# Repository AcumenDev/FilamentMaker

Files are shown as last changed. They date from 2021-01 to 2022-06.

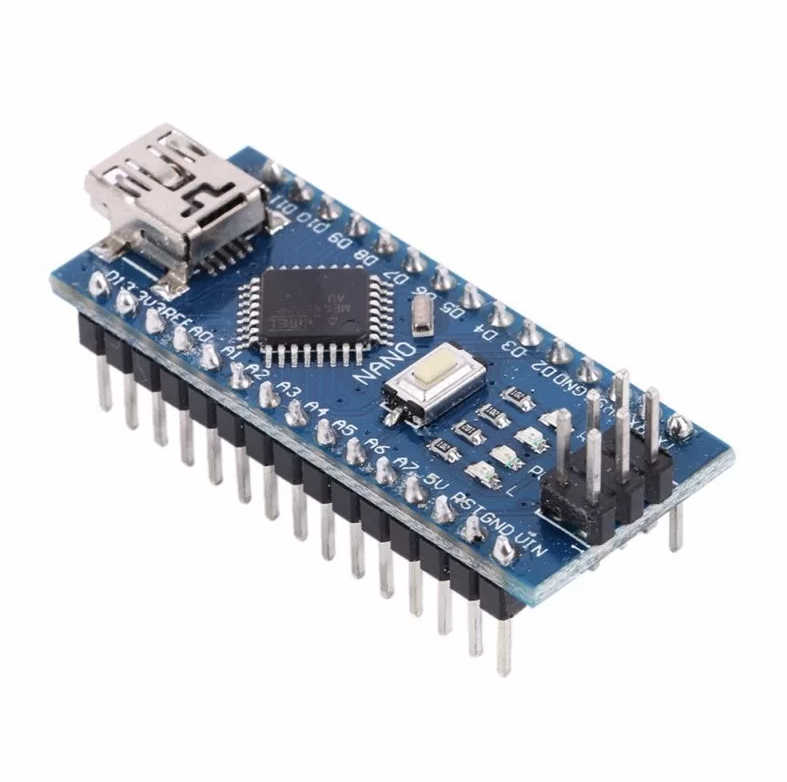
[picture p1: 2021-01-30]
images/nano.jpg

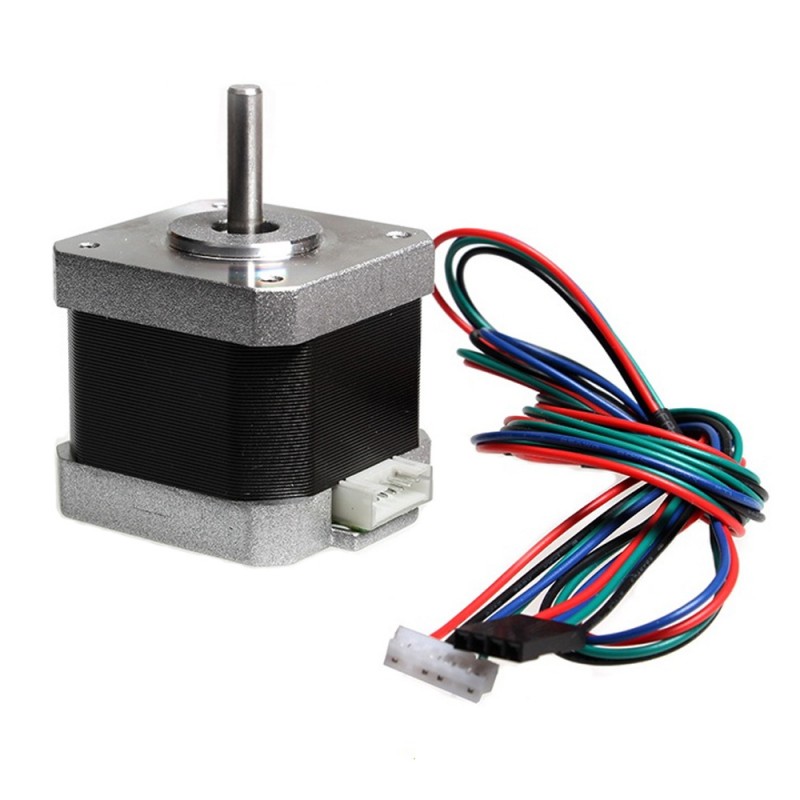
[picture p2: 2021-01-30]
images/stepper-nema17.jpg

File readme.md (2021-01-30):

Модели для печати

* редуктора 
* бутылкореза 
* корпуса для электроники 

находиться в папке models

Прошивка находится в папке src

Текущий список компонентов 

1. Arduino nano 328
1. Плата адаптера терминала WAVGAT для Arduino Nano 3,0
1. Модуль IRF520 для Arduino 
1. алюминиевый радиатор 15*10*25 мм для транзистора TO-220
1. Датчик температуры 100K Ohm NTC 3950 с кабелем
1. резистор 100 кОм
1. нагреватель для 3д принтера 12 вольт 40 ватт 
1. плата для драйвера шагового двигателя 
1. драйвер для шагового двигателя  A4988 или DRV8825 или TMC2208
1. Шаговый двигатель NEMA17 42N.cm 
1. блок питания 12 вольт 5 ампер

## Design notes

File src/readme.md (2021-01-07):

Для сборки и заливки в устройство понадобиться VSCode и плагин к нему platformio

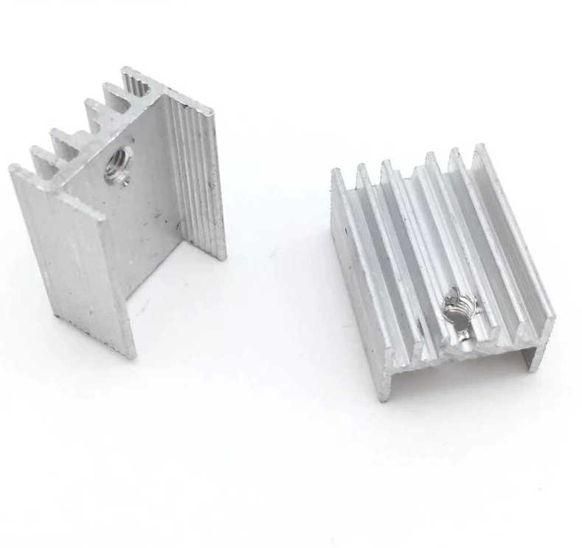
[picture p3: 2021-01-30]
images/radiator.jpg

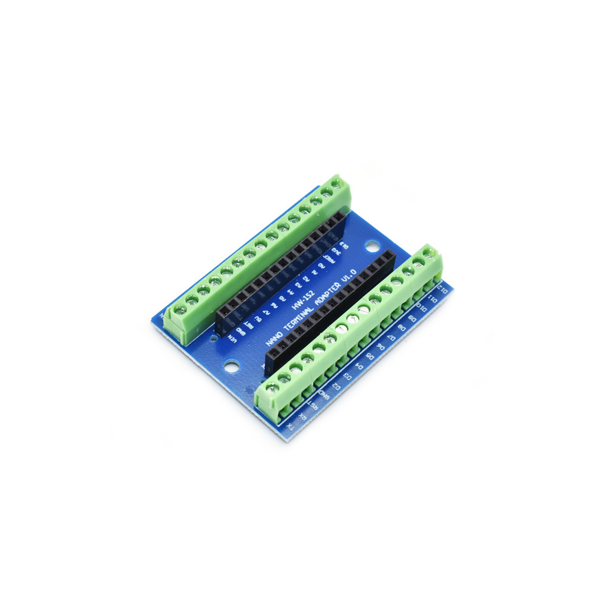
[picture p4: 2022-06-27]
images/Terminal-Adapter--Arduino-NanoV3.jpg

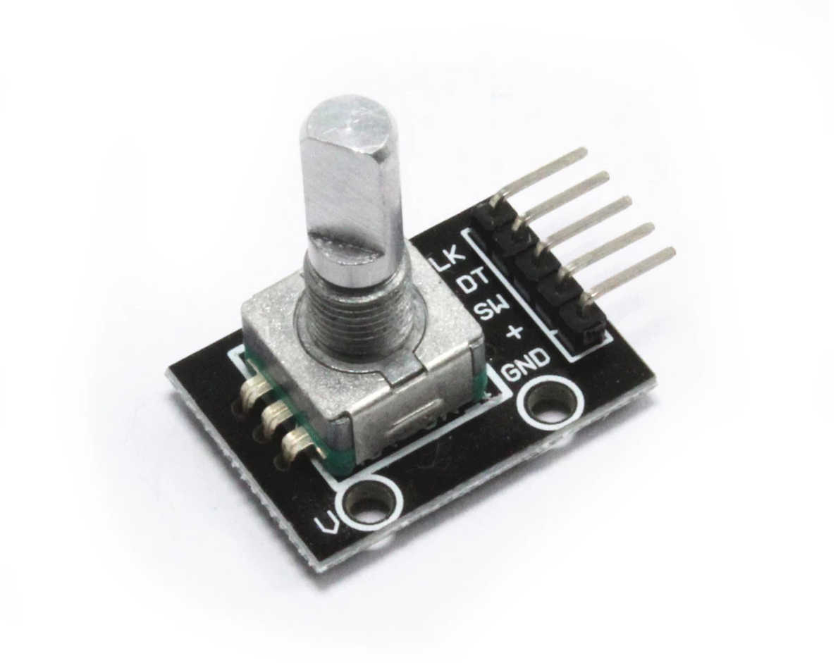
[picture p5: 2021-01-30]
images/encoder.jpg

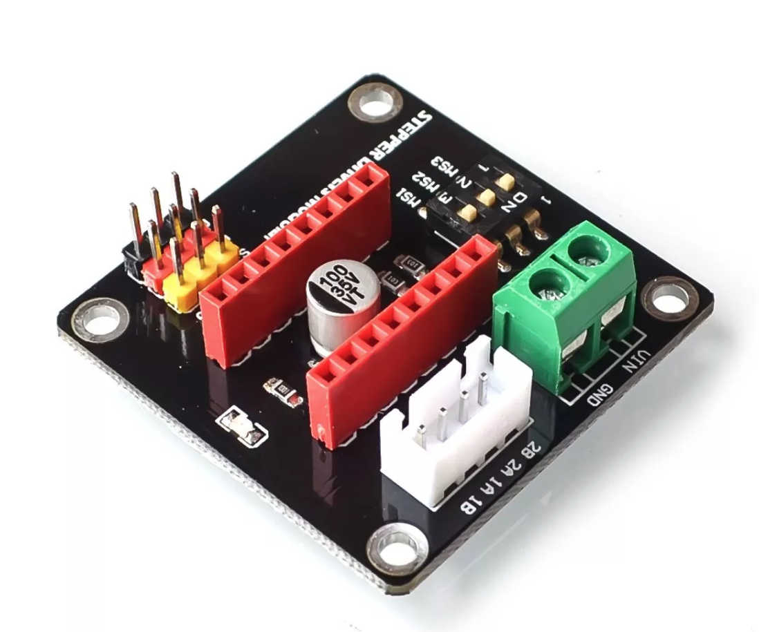
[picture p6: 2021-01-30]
images/driver-board.jpg

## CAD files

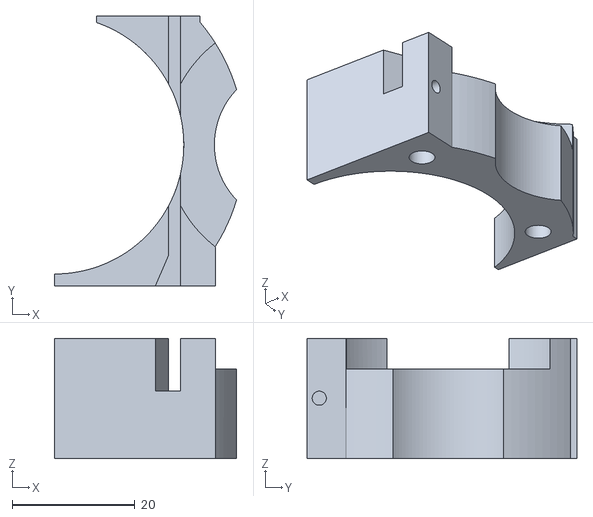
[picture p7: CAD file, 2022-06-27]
models/botle_cut/insert_6mm.stl
29.7 x 44.0 x 19.6

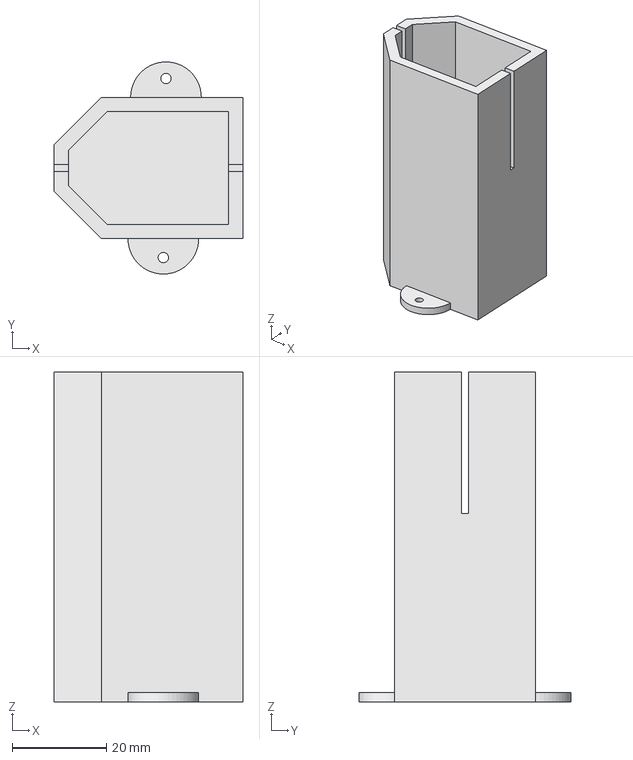
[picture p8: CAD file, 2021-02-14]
models/filter/filter.FCStd
40.0 x 45.0 x 70.0 mm

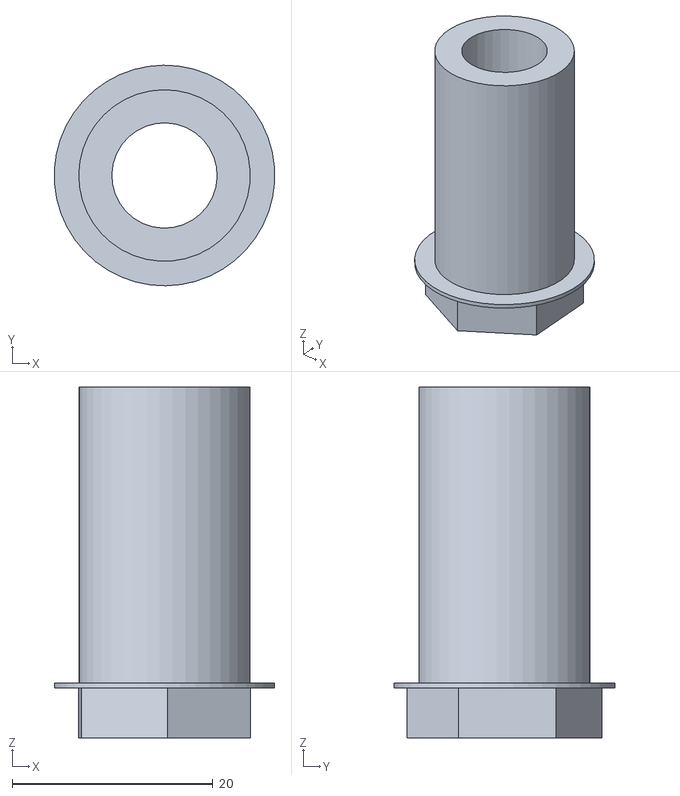
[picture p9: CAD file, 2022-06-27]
models/gearbox/new_gear_box_stl/New_gear_box-Modelinsert_bearing_for_spool001.stl
22.0 x 22.0 x 35.0

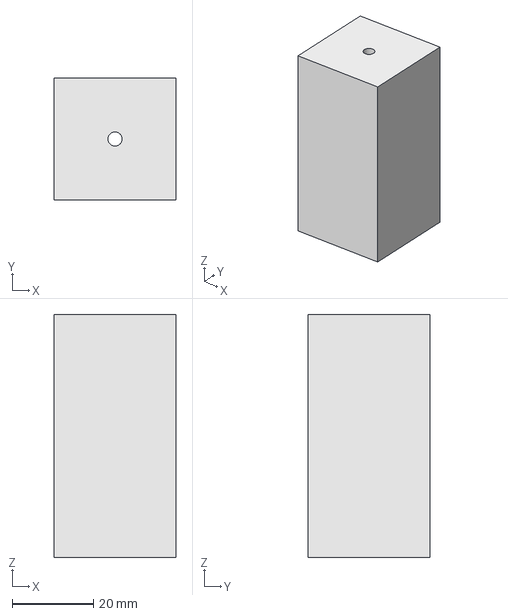
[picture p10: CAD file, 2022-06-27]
models/legs.FCStd
30.0 x 30.0 x 60.0 mm

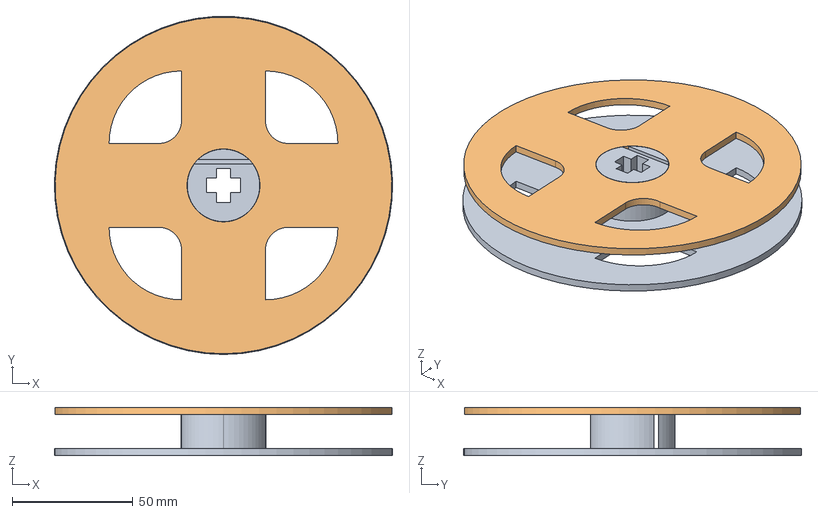
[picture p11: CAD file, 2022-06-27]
models/other/other.FCStd
140.0 x 139.9 x 20.0 mm

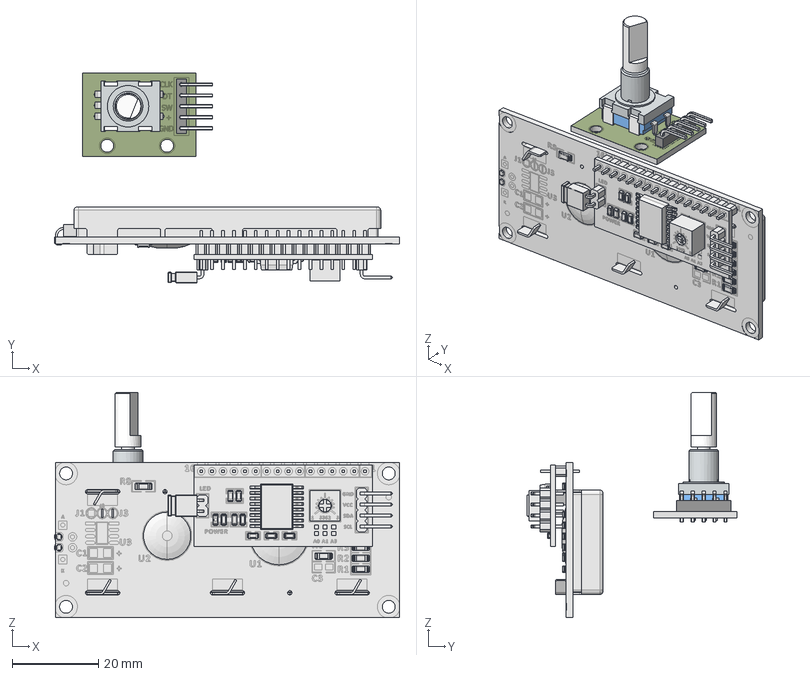
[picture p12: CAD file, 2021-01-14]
models/pcb_box/pcb_box.FCStd
80.2 x 48.7 x 52.3 mm
STEP 1602 Serial LCD Module
pcb
mtg flange
body_encoder
5 pin header
90d pin_header
90d pin_header001
90d pin_header002
90d pin_header003
90d pin_header004
decal_encoder
shaft_encoder

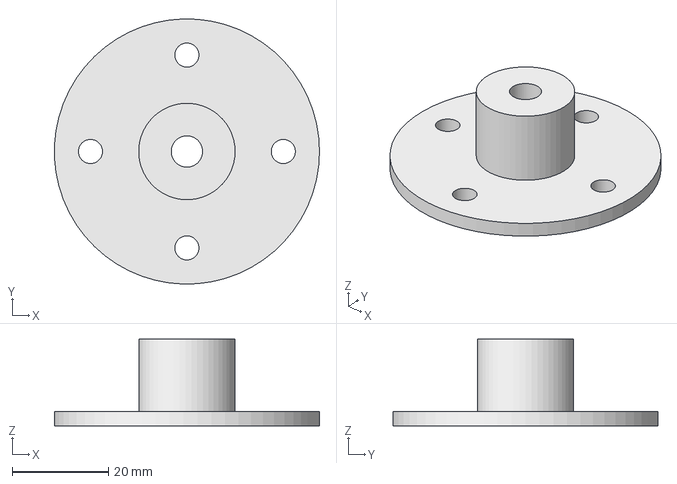
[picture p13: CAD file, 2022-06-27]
models/spool/spool.FCStd
55.0 x 55.0 x 18.0 mm

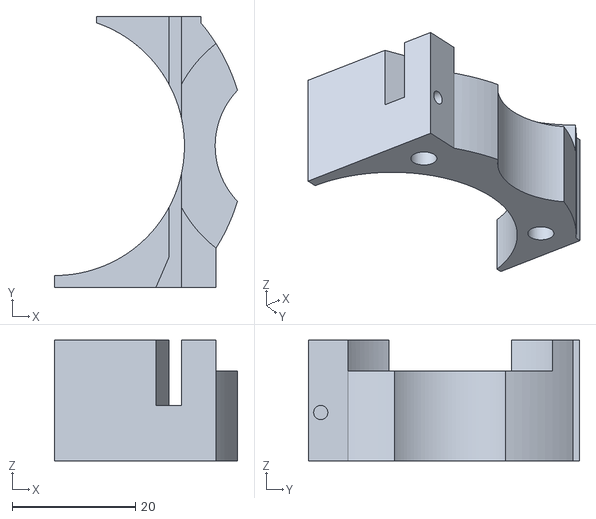
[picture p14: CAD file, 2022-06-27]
models/botle_cut/insert_8mm.stl
29.7 x 44.0 x 19.6

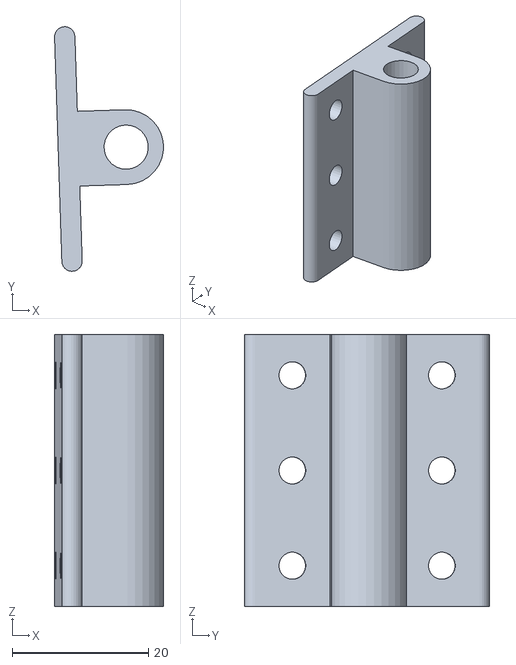
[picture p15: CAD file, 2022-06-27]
models/gearbox/new_gear_box_stl/New_gear_box-ModelCover_screed_botton001.stl
16.0 x 36.0 x 40.0

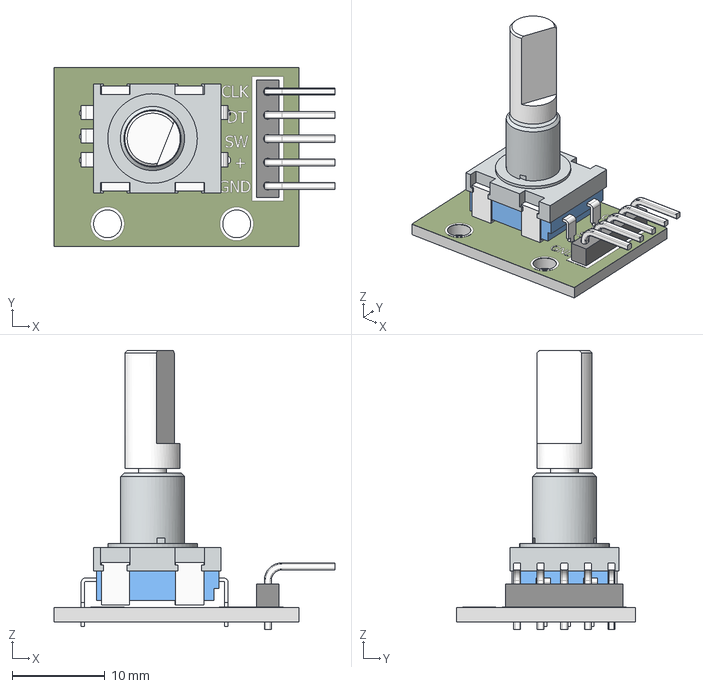
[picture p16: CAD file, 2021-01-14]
models/pcb_box/rotary encoder_chesr_2013.stp
30.3 x 19.3 x 30.1 mm

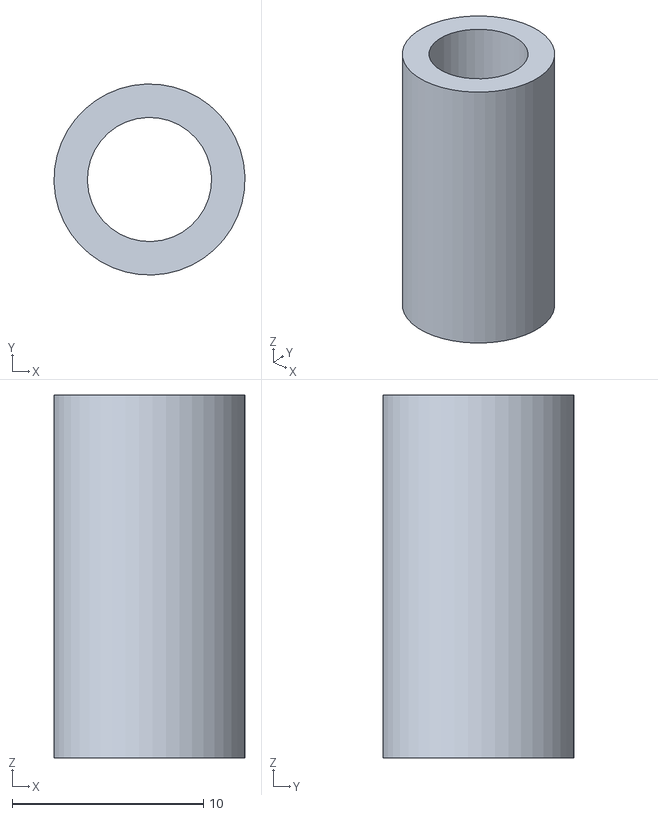
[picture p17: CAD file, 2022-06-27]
models/gearbox/new_gear_box_stl/New_gear_box-ModelInsert_2_gears_2_001.stl
9.99 x 9.99 x 19.0

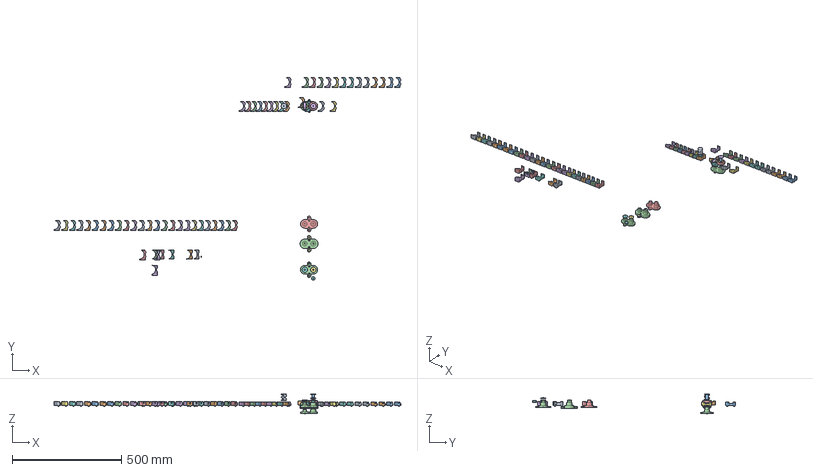
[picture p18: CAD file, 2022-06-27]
models/botle_cut/botle_cut.FCStd
1589.7 x 928.4 x 90.8 mm
M4-Nut
roulement 6203 (d17x40 b12)
roulement 6203 (d17x40 b12)_3
roulement 6203 (d17x40 b12)_2
M4x12-Screw
M4x40-Screw
M4x30-Screw

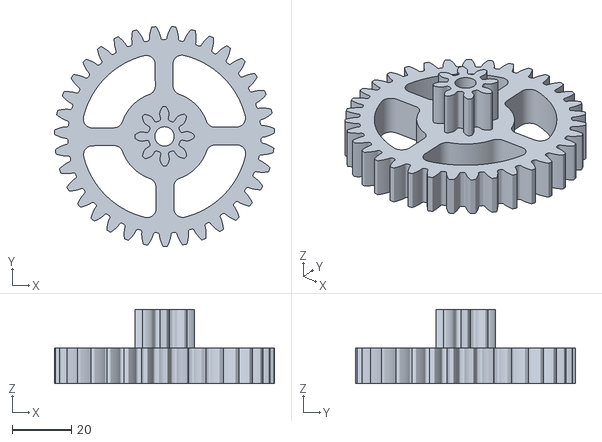
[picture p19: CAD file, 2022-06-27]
models/gearbox/new_gear_box_stl/New_gear_box-Modeltwo_gears001.stl
74.0 x 73.9 x 25.0

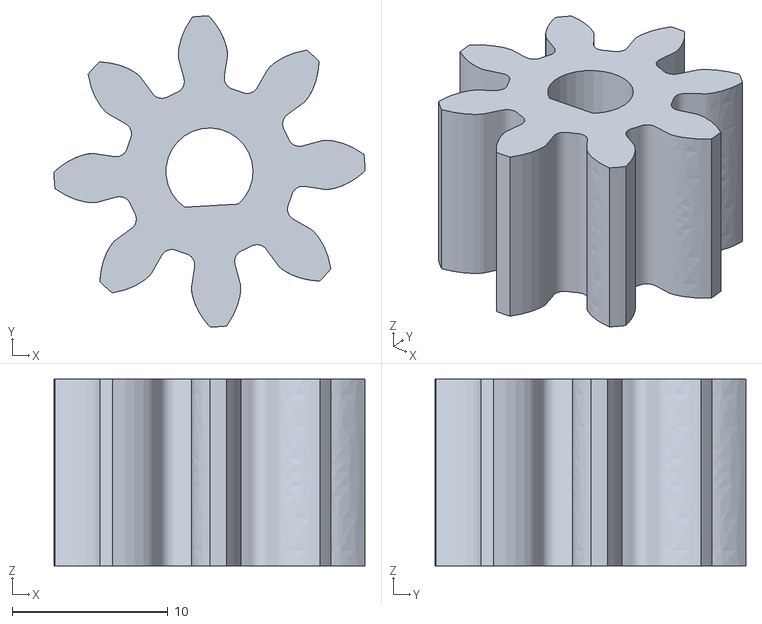
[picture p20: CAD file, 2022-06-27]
models/gearbox/new_gear_box_stl/New_gear_box-Modelgear_motor001.stl
20.0 x 20.0 x 12.0

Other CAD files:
models/botle_cut/insert_7mm.stl
models/botle_cut/insert_9.5mm.stl
models/botle_cut/insert_10mm.stl
models/gearbox/new_gear_box_stl/New_gear_box-ModelCoverScreed003.stl
models/gearbox/new_gear_box_stl/New_gear_box-ModelCap001.stl
models/gearbox/new_gear_box_stl/New_gear_box-ModelClamping_bearing001.stl
models/gearbox/new_gear_box_stl/New_gear_box-ModelGear001.stl
models/gearbox/new_gear_box_stl/New_gear_box-ModelInsert_2_gears_1_001.stl
models/gearbox/new_gear_box_stl/New_gear_box-ModelInsert_3_gears_1_001.stl
models/gearbox/new_gear_box_stl/New_gear_box-ModelInsert_3_gears_2_001.stl
models/gearbox/new_gear_box_stl/New_gear_box-ModelShell_003.stl
models/gearbox/new_gear_box_stl/New_gear_box-ModelShell_1_001.stl
models/gearbox/new_gear_box_stl/New_gear_box-ModelSpool__003.stl
models/gearbox/new_gear_box_stl/New_gear_box-ModelSpool__004.stl
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

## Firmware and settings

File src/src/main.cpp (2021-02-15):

#include "Menu.hpp"
#include "Motor.hpp"
#include "StopSensor.hpp"
#include "TemperaturePid.hpp"
#include "TemperatureSensor.hpp"
#include "TemperatureValueHolder.hpp"
#include "Values.hpp"
#include "ValuesSaver.hpp"
#include "menu/RunMenuItem.hpp"
#include "menu/TemperatureMenuItem.hpp"
#include "menu/UnwindMenuItem.hpp"

Values values;
ValuesSaver valuesSaver;
TemperatureValueHolder tempValueHolder;
Motor motor(&values);
TemperatureSensor temperatureSensor;
TemperaturePid temperaturePid(&values);
auto runMenuItem = RunMenuItem(&values);
auto tempMenuItem = TemperatureMenuItem(&values, &tempValueHolder);
auto unwindMenuItem = UnwindMenuItem(&values);
MenuItem *menus[MENU_ITEMS] = {&runMenuItem, &tempMenuItem, &unwindMenuItem};
Menu menu(menus);
StopSensor stopSensor(&values);

unsigned long currentMillis = 0;

void setup() {
  Serial.begin(9600);
  Serial.println("[Main] Start");
  Serial.println("[Main] Init start");
  valuesSaver.init();
  values.init();
  values.addObserver(&motor);
  values.addObserver(&temperaturePid);
  values.addObserver(&valuesSaver);
  motor.init();
  temperatureSensor.init(&tempValueHolder);
  temperaturePid.init(&tempValueHolder);
  menu.init();
  stopSensor.init();
  Serial.println("[Main] Init end");
}

void loop() {
  currentMillis = millis();
  temperatureSensor.update(currentMillis);
  temperaturePid.update(currentMillis);
  menu.update(currentMillis);
  stopSensor.update(currentMillis);
}

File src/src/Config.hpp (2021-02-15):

#ifndef Config_HPP
#define Config_HPP
#include <Arduino.h>

/// encoders pins
static const int PIN_ENCODER_CLK = 7;
static const int PIN_ENCODER_DT = 6;
static const int PIN_ENCODER_SW = 5;
///
/// motor driver pins
static const short PIN_DRIVER_STEP = 3;
static const short PIN_DRIVER_DIR = 4;
static const short PIN_DRIVER_EN = 2;
///
/// NTC Temperature sensor pin
static const short PIN_TEMPERATURE = A0;
/// mosfet pin
static const short PIN_PWM_HEAD = 9;
///

///StopSensor
static const short PIN_STOP_SENSOR = A1;
///


/// motor microstep
static const int MOTOR_MICRO_STEPS = 8;
///
/// PID temperature
static const double PID_KP = 14;
static const double PID_KI = 0.93;
static const double PID_KD = 59.87;
///







static const int EEPROM_ADR_INIT_FLAG = 0;
static const int EEPROM_ADR_HEATER_TEMPERATURE = 2;
static const int EEPROM_ADR_MOTOR_SPEED = 4;
static const int EEPROM_ADR_MOTOR_UNWIND_SPEED = 6;


#endif

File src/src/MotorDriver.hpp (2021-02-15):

#ifndef MotorDriver_hpp
#define MotorDriver_hpp
#include <Arduino.h>
#include <TimerOne.h>

enum Direction { Forward, Backwards };

class MotorDriver {
private:
  static short _pinStep;
  const short pinDir;
  const short pinEn;

  const int steps;
  const int microsteps;

  static void tickMotor();

public:
  MotorDriver(short pinStep, short pinDir, short pinEn, int steps = 200,
              int microsteps = MOTOR_MICRO_STEPS);

  virtual ~MotorDriver() {}
  void init();
  void start(int rpm);
  void stop();
  void setDirection(Direction dir);
  static long getInterval(int rpm, int microsteps, int steps);
};

MotorDriver::MotorDriver(short pinStep, short pinDir, short pinEn, int steps,
                         int microsteps)
    : pinDir(pinDir), pinEn(pinEn), steps(steps), microsteps(microsteps) {

  _pinStep = pinStep;
}

void MotorDriver::init() {
  pinMode(_pinStep, OUTPUT);
  pinMode(pinDir, OUTPUT);
  pinMode(pinEn, OUTPUT);
  digitalWrite(_pinStep, LOW);
  digitalWrite(pinDir, LOW);
  digitalWrite(pinEn, HIGH);
  Timer1.attachInterrupt(MotorDriver::tickMotor);
}

void MotorDriver::start(int rpm) {
  Timer1.initialize(MotorDriver::getInterval(rpm, microsteps, steps));
  digitalWrite(pinEn, LOW);
}

void MotorDriver::stop() {
  Timer1.stop();
  digitalWrite(_pinStep, LOW);
  digitalWrite(pinEn, HIGH);
}
void MotorDriver::tickMotor() {
  digitalWrite(_pinStep, 1);
  delayMicroseconds(4);
  digitalWrite(_pinStep, 0);
}

long MotorDriver::getInterval(int rpm, int microsteps, int steps) {
  return 60.0 * 1000000L / steps / microsteps / rpm;
}

void MotorDriver::setDirection(Direction dir) {
  switch (dir) {
  case Forward: {
    digitalWrite(pinDir, LOW);
    break;
  }
  case Backwards: {
    digitalWrite(pinDir, HIGH);
    break;
  }
  }
}

short MotorDriver::_pinStep;

#endif

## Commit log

2021-01-07 начальное меню, старт стоп, изменение скорости
2021-01-09 added ntc 100k temperature sensor
2021-01-14 added pid
    [pcb_box.FCStd, rotary encoder_chesr_2013.stp]
2021-01-30 Фиксы после тестов
2021-01-30 почитстил код
2021-01-30 добавил фото компонентов
2021-02-06 новое меню
2021-02-14 Обновил модель бутылкореза, подкоректировал настройки пид
    [botle_cut.FCStd, filter.FCStd, insert_10mm.stl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]
2021-02-15 сохранение в eeprom, резмотка, датчик выключения
    [other.FCStd]
2022-06-27 Добавил stl для печати
    [New_gear_box-ModelCap001.stl, New_gear_box-ModelClamping_bearing001.stl, New_gear_box-ModelCoverScreed003.stl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]
